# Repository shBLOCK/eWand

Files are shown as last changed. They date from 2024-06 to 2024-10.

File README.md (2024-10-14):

# ⚡eWand: a smart portable electrostatic charge generator

**This project is still highly WIP, as of right now, it does generate charge, but not much control is possible yet.**
<br>
This project is a group project, deriving from my school's project-based learning month.
<br>
Documentation is WIP.

## ⚙️Main features
- Portable
- Fully solid-state operation
- Precisely controllable output
- Output charge measurement (WIP)
- Wireless connectivity
  - Remote configuration & control
  - Data feedback

## Usages
- Physics teaching aid
- ESD testing
- ...

## Notes
- This project is inspired by [Join The Technicians's device](https://www.youtube.com/watch?v=TUDd5lzepgE), but adds more "smart" features to make it more useful as a teaching aid device and for other purposes.

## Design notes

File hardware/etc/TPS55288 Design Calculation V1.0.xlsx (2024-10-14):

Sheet: Design Calculation
Design Tool for TPS55288
V1.0 (06/14/2020)
This tool is designed to aid the user in designing the TPS55288 buck-boost converter. Refer to TPS55288 datasheet for detail design precedure and all equations.
 |  | User input value
 |  | Calculated value
 |  | No use or internal value
Description | Value | Units | Instructions/Comments | Schematic
Component Value
Vin(min) | 3 | V | >=2.7V
Vin(max) | 16 | V | <=36V
Output feedback selection | Internal |  | Select internal feedback or external feedback
Vout | 12.00 | V | Must be lower than or equal to the 1.063x Vout(max)
Vout(max) | 20.0 | V | Select 5V, 10V, 15V, 20V maximum Vout with Vref set to 1.129V
Iout(max) | 5 | A | Maximum output current
Register VREF | 0230 | Hex | Register 00H and 01H value for Vref
VCC | External |  | Select internal VCC or use external VCC power supply
Switching Mode at light load | FPWM |  | Select Forced PWM or Auto PFM mode at light load
I2C address | 74 | Hex | Select I2C slave address
R6 | 51100 | Ω | Mode setting resistor
R7 | 100000.0 | Ω | Up resistor value of the extenral feedback resistor value. It is recommended to 100kΩ
R8 recommended | 5982.7 | Ω | Bottom resistor value of the external feedback resistor divider
Enable Output current limit | Enable |  | Enable output current limit
Iout(limit) | 6.3 | A | Output current limit setting
R1 | 10 | mΩ | Output current sensing resistor
Register 02H | FE | Hex | Register 02H value for current setting. Iout(max)*R1 must be less than 63.5mV
ΔIout(Cout_rms) | 8.66 | Arms | The equivalent output capacitor current ripple spec must be higher than this value.
ΔIin(Cin_rms) | 2.17 | Arms | The equivalent input capacitor current ripple spec must be higher than this value
f(sw) | 394870 | Hz | Typical switching frequency
R2 recommended | 49999.58087 | Ω | Switching frequency setting resistor
Frequency dithering f(mod) | 490 | Hz | Modulation frequency for spread spectrum
C8 recommended | 1.457738167e-08 | F |  | Register Setting
ΔVout(pk-pk) | 0.05 | Vpp | Maximum desired output ripple solely due to output capacitance (ignores ESR)
Cout(min) recommended | 0.0001899359283 | F | Minimum output capacitance needed for Vout ripple requirement | Register Name | Address | b7 | b6 | b5 | b4 | b3 | b2 | b1 | b0 | HEX Value
C2 actual | 1e-05 | F | Effective ceramic capacitance at VOUT. Need to consider the derating with DC bias voltage | VREF_L | 00H | VREF[7] | VREF[6] | VREF[5] | VREF[4] | VREF[3] | VREF[2] | VREF[1] | VREF[0] | 30
 |  |  |  |  |  | 0 | 0 | 1 | 1 | 0 | 0 | 0 | 0
C3 actual | 0.00044 | F | Effective electrolytic capacitance. Need to consider the derating with DC bias voltage | VREF_H | 01H | Reserved | Reserved | Reserved | Reserved | Reserved | Reserved | VREF[9] | VREF[8] | 02
 |  |  |  |  |  | 0 | 0 | 0 | 0 | 0 | 0 | 1 | 0
ESR of C3 | 0.009 | Ω | Equivalent ESR if multiple high ESR electrolytic capacitors in parallel | I_LIMIT | 02H | ILIM_EN | I_LIM[6] | I_LIM[5] | I_LIM[4] | I_LIM[3] | I_LIM[2] | I_LIM[1] | I_LIM[0] | FE
 |  |  |  |  |  | 1 | 1 | 1 | 1 | 1 | 1 | 1 | 0
ΔVin(pk-pk) | 0.05 | Vpp | Maximum desired input ripple due to solely to input capacitance at buck mode | VOUT_SR | 03H | Reserved | Reserved | OCPD[1] | OCPD[0] | Reserved | Reserved | VOSR[1] | VOSR[0] | 31
 |  |  |  |  |  | 0 | 0 | 1 | 1 | 0 | 0 | 0 | 1
Cin(min) recommended | 6.331197609e-05 | F | Minimum input capacitance needed for Vin ripple requirement | VOUT_FS | 04H | FBSEL | Reserved | Reserved | Reserved | Reserved | Reserved | INTFB[1] | INTFB[0] | 03
 |  |  |  |  |  | 0 | 0 | 0 | 0 | 0 | 0 | 1 | 1
Cin actual | 4e-05 | F | effective output capacitance. Need to consider the derating with DC bias voltage when using ceramic cap | CDC | 05H | SCMASK | OCMASK | OVMASK | Reserved | INTCDC | CDC[2] | CDC[1] | CDC[0] | E0
 |  |  |  |  |  | 1 | 1 | 1 | 0 | 0 | 0 | 0 | 0
η estimate | 91.0% |  | Efficiency estimate. Correct it after getting the calculated efficiency | MODE | 06H | OE | FSWDBL | HICCUP | DISCHG | VCCSEL | I2CADD | PFMSEL | MODEST | 39
 |  |  |  |  |  | OFF -0 | DIS -0 | ENA -1 | ENA -1 | EXT -1 | 74H -0 | PFM -0 | INT -1
K | 0.5 |  | Fraction of maximum average inductor current that is ripple current (0.2-0.6 typically) | STATUS | 07H | SCP | OCP | OVP | Reserved | Reserved | Reserved | STATUS1 | STATUS0 | 00
 |  |  |  |  |  | 0 | 0 | 0 | 0 | 0 | 0 | 0 | 0
L1 recommended min | 5.185250842e-07 | H | L1's minimum recommended inductance value to meet inductor current ripple ratio at boost mode with Vin_min
L1 actual | 2.2e-06 | H
I(Lrms) max | 21.99 | Arms | Inductor maximum RMS current
I(Lpeak) max | 23.27 | A | The inductor (L1) is recommended to have saturation current rating 30% higher than this value.
I(Lvalley) max | 20.68 | A
Average Inductor Limit | 16.5 | A | Desired typical average inductor current limit. ±2.5A tolerance
R5 recommended | 20000 | Ω
CDC compensation selection | Internal |  | Internal CDC when using internal Vout feedback. External CDC when using external Vout feedback.
Internal CDC voltage ratio | 0 | mV/mV | ΔVout / (VISP-VISN)
External CDC voltage ratio | 0 | mV/mV | ΔVout / (VISP-VISN)
R4 recommend | floating | Ω | Recommended R4 for external CDC setting
OCP delay time | 12.0 | ms | Set the output current limit response time
VOUT change slew rate | 2.50 | V/ms | Set the output voltage change slew rate during vPPS
Enable SCP indication | Enable |  | Enable or disable the output short circuit indication
Enable OCP indication | Enable |  | Enable or disable the output over current indication
Enable OVP indication | Enable |  | Enable or disable the output over voltage indication
Loop Compensation Calculation in FPWM CCM mode |  |  |  | Bode Plot
Vin | 3.0 | V | Check both buck and boost mode by changing Vin and Vout. The loop must have enough phase margin and gain margin
Vout | 12.0 | V
Buck or Boost? | Boost |  | Calculate open loop compensate at buck mode or boost mode
gm_PS | 19 | S | Power stage gm of IL/Vcomp
fp_PS | 294.7313761 | Hz | Power stage pole of Rload and Cout
fz_RHP | 8986.105116 | Hz | Right half plane zero in boost mode
fz_ESR | 40190.64219 | Hz | ESR zero of the output cap
f(BW) desired | 3000 | Hz | Should be less than 1/5*fzRPH and 1/10*fsw
gm_EA | 0.00019 | S | Error amplifier gm
R3 recommended | 182962.0795 | Ω
R3 actual | 75000 | Ω | COMP pin has internal 2k resistor in seriese with R3
C7 recommended | 6.889824376e-09 | F | Set the compensation fz = fco/10
C7 actual | 6.8e-09 | F
fz_COMP | 303.9628401 | Hz | Loop compensation zero frequency
C6 recommended | 2.446457175e-10 | F | The lower zero of the Cout's ESR zero and boost right half plane zero should be cancelled by the R3*(C6*C7/(C6+C7)) pole
C6 actual | 1e-10 | F
fp2_COMP | 20371.41248 | Hz | Have internal 3pF cap between COMP and GND
Efficiency in buck CCM mode or boost CCM mode with maximum Iout
Vin | 3.7 | V | Vin for efficiency estimation at desired Vout and Iout(max)
I(Lrms) | 17.84 | A | Inductor RMS current
I(Lpeak) | 19.29 | A | Inductor peak current
I(Lvalley) | 16.35 | A | Inductor valley current
DCR of L1 | 0.00255 | Ω | Inductor series resistance per inductor datasheet
Buck HSFET Rdson | 0.0065 | Ω | HSFET on-resistance
Buck HSFET Qg | 7e-09 | C | Total Qg at Vgs=5V
Buck HSFET Coss | 2.7e-10 | F | HSFET output capacitance when VDS=VIN
Buck HSFET rise time | 3.3e-09 | s | Estimate of SW1 node 10-90% rise time from measurement
Buck HSFET fall time | 4.3e-09 | s | Estimate of SW1 node 10-90% fall time from measurement
Buck LSFET Rdson | 0.0065 | Ω | HSFET on-resistance
Buck LSFET Qg | 7e-09 | C | Total Qg at Vgs=5V
Buck LSFET Qrr | 1.72e-08 | C | Reverse recovery charge of the low side FET
Buck LSFET dead time | 1e-08 | s | Dead time during the switching
Buck LSFET diode voltage | 0.7 | V | Estimate of body diode voltage of the HSFET
Boost LSFET Rdson | 0.0071 | Ω | LSFET on-resistance in TPS55288 is 7.1mΩ at 25°C. Temperature coefficient is 0.4%/°C. Correct it when at high Tj
Boost LSFET fall time | 1.3e-08 | s | Estimate of SW node 10-90% fall time from measurement
Boost LSFET rise time | 1.3e-08 | s | Estimate of SW node 10-90% rise time from measurement
Boost HSFET Rdson | 0.0076 | Ω | HSFET on-resistance in TPS55288 is 7.6mΩ at 25°C. Temperature coefficient is 0.4%/°C. Correct it when at high Tj
Boost HSFET dead time | 2e-08 | s | Dead time during the switching
Boost HSFET diode voltage | 1.0 | V | Estimate of body diode voltage of the HSFET
Buck snubber Csnubber | 0 | F | Capacitance of snubber at buck side
Boost snubber Csnubber | 0 | F | Capacitance of snubber at boost side
Rpcb on power path | 2.0 | mΩ | PCB trace resistance on power path from Vin to Vout cap
Rpcb Pd | 636.552483 | mW | Power losses on PCB trace
Inductor DCR Pd | 811.6044158 | mW | Includes losses from DC resistance drop only
Inductor core & AC Pd | 344 | mW | Core and AC loss of inductor. Use inductor vendor's formula to estimate. 344mW is the power loss of XAL1010-472 running at 400kHz with Ilrms=5.21A and Ilripple=2.55A at 400kHz.
TPS55288 Pd | 3879.236161 | mW | Power loss on TPS55288
Rsense Pd | 250 | mW | Power loss on output current sense resistor
Snubber Pd | 0 | mW | Power loss on snubber
Buck HSFET Pd | 2068.79557 | mW | Power loss on buck high side FET
Buck LSFET Pd | 0 | mW | Power loss on buck low side FET
Cout Pd | 489.886869 | mW | Power loss on ESR of the output capacitor in boost mode | 8.8e-08 | 15.88575882 | 38.54611551
η - calculated | 87.6% |  | Efficiency at Iout_max
ΘJA | 37 | °C/W | TPS55288 junction to ambient thermal resistance on EVM. The actual ΘJA depends on the PCB design.
TPS55288 temperature rise | 143.5 | °C | The top case temperature of IC is very close to the Junction temperature because ΨJT=0.6°C/W
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

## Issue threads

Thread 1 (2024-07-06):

EMP interfering debug and sysbus cable signals

shBLOCK, 2024-07-06:
With the current hardware, whenever a discharge pulse happens, the MCU resets.
This is the result of the EMP generating a pulse on the reset line in the debug FPC, this is mostly mitigated by adding a capacitor (eg. 10uF) near the RUN pin to ground.
Further testing is required to see if the sysbus might be interfered in this way.

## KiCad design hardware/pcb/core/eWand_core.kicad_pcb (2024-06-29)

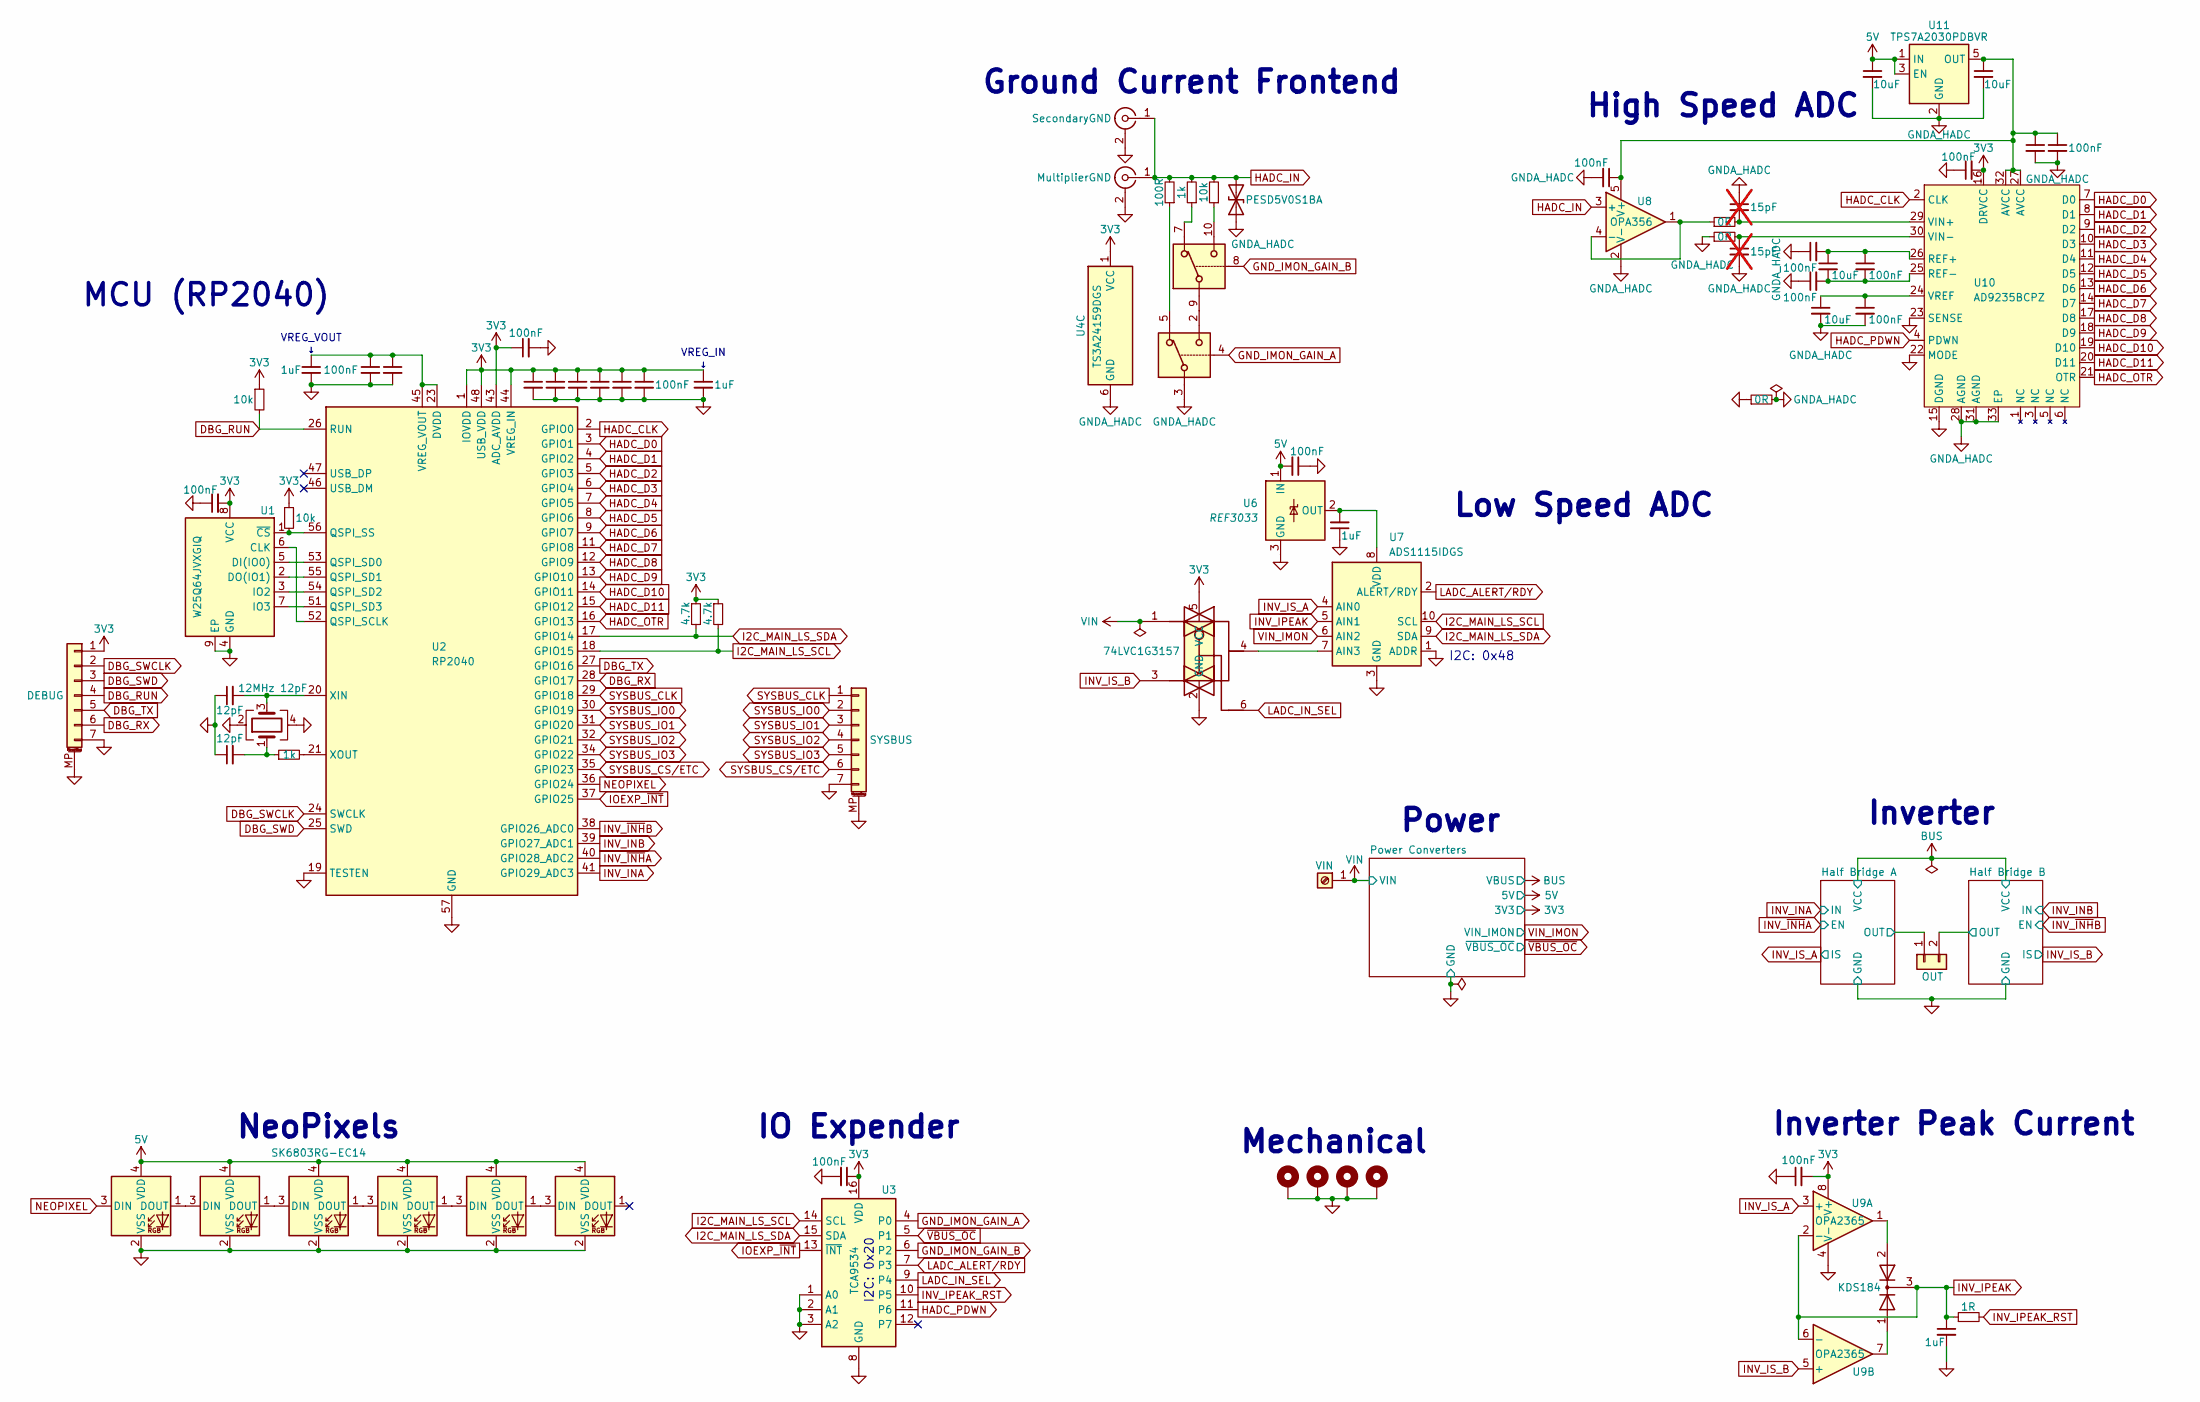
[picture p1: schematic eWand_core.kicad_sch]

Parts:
C1, C5, C6, C7, C8, C9, C10, C11, C12, C13, C15, C16, C18, C21, C22, C23, C26, C27, C30, C32, C33: 100nF; C_0402_1005Metric; LCSC C307331
C2, C3: 12pF; C_0402_1005Metric; LCSC C1547
C4, C14, C17: 1uF; C_0402_1005Metric; LCSC C52923
C19, C20: 15pF; C_0402_1005Metric; LCSC C1548; not fitted
C24, C25, C28, C31: 10uF; C_0402_1005Metric; LCSC C15525
C29: 1uF; C_0805_2012Metric; LCSC C28323
D1, D2, D3, D4, D5, D6: SK6803RG-EC14; LED_SK6812_EC15_1.5x1.5mm; LCSC C18548258
D7: PESD5V0S1BA; D_SOD-323; LCSC C19224
D8: KDS184; SOT-23; LCSC C112694
H1, H2, H3, H4: MountingHole_Pad; MountingHole_2.2mm_M2_Pad_Via
J1: DEBUG; TE_0-1734839-7_1x07-1MP_P0.5mm_Horizontal; LCSC C2911879
J2: SYSBUS; TE_0-1734839-7_1x07-1MP_P0.5mm_Horizontal; LCSC C262232
J3: SecondaryGND; U.FL_Molex_MCRF_73412-0110_Vertical; LCSC C411563
J4: MultiplierGND; U.FL_Molex_MCRF_73412-0110_Vertical; LCSC C411563
J5: VIN; T31000; LCSC C481468
J6: OUT; VH3.96-2AW; LCSC C722831
R1, R2: 10k; R_0402_1005Metric; LCSC C25744
R3: 1k; R_0402_1005Metric; LCSC C11702
R4, R5: 4.7k; R_0402_1005Metric; LCSC C25900
R6: 100R; C_0603_1608Metric; LCSC C22775
R7: 1k; C_0603_1608Metric; LCSC C21190
R8: 10k; C_0603_1608Metric; LCSC C25804
R9, R10: 0R; R_0402_1005Metric; LCSC C17168
R11: 0R; R_0603_1608Metric; LCSC C21189
R12: 1R; R_0402_1005Metric; LCSC C185446
U1: W25Q64JVXGIQ; WSON-8-1EP_4x4mm_P0.8mm_EP2.2x3mm; LCSC C2940195
U2: RP2040; QFN-56-1EP_7x7mm_P0.4mm_EP3.2x3.2mm; LCSC C2040
U3: TCA9534; TSSOP-16_4.4x5mm_P0.65mm; LCSC C206010
U4: TS3A24159DGS; TSSOP-10_3x3mm_P0.5mm; LCSC C129329
U5: 74LVC1G3157; SOT-363_SC-70-6; LCSC C38663
U6: REF3033; SOT-23; LCSC C36658
U7: ADS1115IDGS; TSSOP-10_3x3mm_P0.5mm; LCSC C37593
U8: OPA356; SOT-23-5; LCSC C183100
U9: OPA2365; SOIC-8_3.9x4.9mm_P1.27mm; LCSC C130011
U10: AD9235BCPZ; LFCSP-32-1EP_5x5mm_P0.5mm_EP3.1x3.1mm; LCSC C653330
U11: TPS7A2030PDBVR; SOT-23-5; LCSC C963429
Y1: 12MHz 12pF; Crystal_SMD_3225-4Pin_3.2x2.5mm; LCSC C70565

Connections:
3V3: C1.2, C7.1, C8.1, C9.1, C10.1, C11.1, C12.1, C13.1, C14.1, C15.1, C21.2, C30.2, J1.1, R1.1, R2.1, R4.1, R5.1, U1.8 (VCC), U2.1 (IOVDD), U2.10 (IOVDD), U2.22 (IOVDD), U2.33 (IOVDD), U2.42 (IOVDD), U2.43 (ADC_AVDD), U2.44 (VREG_IN), U2.48 (USB_VDD), U2.49 (IOVDD), U3.16 (VDD), U4.1 (VCC), U5.5 (VCC), U9.8 (V+), U10.16 (DRVCC); also elsewhere on the board
5V: C16.2, C28.1, D1.4 (VDD), D2.4 (VDD), D3.4 (VDD), D4.4 (VDD), D5.4 (VDD), D6.4 (VDD), U6.1 (IN), U11.1 (IN), U11.3 (EN); also elsewhere on the board
/Half Bridge A/OUT: J6.1; also elsewhere on the board
/Half Bridge B/OUT: J6.2; also elsewhere on the board
DBG_RUN: J1.4, R1.2, U2.26 (RUN)
DBG_RX: J1.6, U2.28 (GPIO17)
DBG_SWCLK: J1.2, U2.24 (SWCLK)
DBG_SWD: J1.3, U2.25 (SWD)
DBG_TX: J1.5, U2.27 (GPIO16)
GND: C1.1, C2.1, C3.1, C4.2, C5.2, C6.2, C7.2, C8.2, C9.2, C10.2, C11.2, C12.2, C13.2, C14.2, C15.2, C16.1, C17.1, C21.1, C29.2, C30.1, D1.2 (VSS), D2.2 (VSS), D3.2 (VSS), D4.2 (VSS), D5.2 (VSS), D6.2 (VSS), H1.1, H2.1, H3.1, H4.1, J1.7, J1.MP (MountPin), J2.7, J2.MP (MountPin), J3.2 (Ext), J4.2 (Ext), R11.1, U1.4 (GND), U1.9 (EP), U2.19 (TESTEN), U2.57 (GND), U3.1 (A0), U3.2 (A1), U3.3 (A2), U3.8 (GND), U5.2 (GND), U6.3 (GND), U7.1 (ADDR), U7.3 (GND), U9.4 (V-), U10.15 (DGND), U10.22 (MODE), U10.23 (SENSE), Y1.2, Y1.4; also elsewhere on the board
GNDA_HADC: C18.2, C19.1, C20.2, C22.1, C23.1, C24.2, C27.2, C28.2, C31.2, C32.2, C33.2, D7.1 (A1), R10.1, R11.2, U4.3, U4.6 (GND), U8.2 (V-), U10.28 (AGND), U10.31 (AGND), U10.33 (EP), U11.2 (GND)
GND_IMON_GAIN_A: U3.4 (P0), U4.4
GND_IMON_GAIN_B: U3.6 (P2), U4.8
HADC_CLK: U2.2 (GPIO0), U10.2 (CLK)
HADC_D0: U2.3 (GPIO1), U10.7 (D0)
HADC_D1: U2.4 (GPIO2), U10.8 (D1)
HADC_D2: U2.5 (GPIO3), U10.9 (D2)
HADC_D3: U2.6 (GPIO4), U10.10 (D3)
HADC_D4: U2.7 (GPIO5), U10.11 (D4)
HADC_D5: U2.8 (GPIO6), U10.12 (D5)
HADC_D6: U2.9 (GPIO7), U10.13 (D6)
HADC_D7: U2.11 (GPIO8), U10.14 (D7)
HADC_D8: U2.12 (GPIO9), U10.17 (D8)
HADC_D9: U2.13 (GPIO10), U10.18 (D9)
HADC_D10: U2.14 (GPIO11), U10.19 (D10)
HADC_D11: U2.15 (GPIO12), U10.20 (D11)
HADC_IN: D7.2 (A2), J3.1 (In), J4.1 (In), R6.2, R7.2, R8.2, U8.3 (+)
HADC_OTR: U2.16 (GPIO13), U10.21 (OTR)
HADC_PDWN: U3.11 (P6), U10.4 (PDWN)
I2C_MAIN_LS_SCL: R5.2, U2.18 (GPIO15), U3.14 (SCL), U7.10 (SCL); also elsewhere on the board
I2C_MAIN_LS_SDA: R4.2, U2.17 (GPIO14), U3.15 (SDA), U7.9 (SDA); also elsewhere on the board
INV_INA: U2.41 (GPIO29_ADC3); also elsewhere on the board
INV_INB: U2.39 (GPIO27_ADC1); also elsewhere on the board
INV_IPEAK: C29.1, D8.3 (K), R12.1, U7.5 (AIN1), U9.2 (-), U9.6 (-)
INV_IPEAK_RST: R12.2, U3.10 (P5)
INV_IS_A: U7.4 (AIN0), U9.3 (+); also elsewhere on the board
INV_IS_B: U5.3, U9.5 (+); also elsewhere on the board
INV_~INHA: U2.40 (GPIO28_ADC2); also elsewhere on the board
INV_~INHB: U2.38 (GPIO26_ADC0); also elsewhere on the board
IOEXP_~INT: U2.37 (GPIO25), U3.13 (~INT)
LADC_ALERT/RDY: U3.7 (P3), U7.2 (ALERT/RDY)
LADC_IN_SEL: U3.9 (P4), U5.6
NEOPIXEL: D1.3 (DIN), U2.36 (GPIO24)
unnamed: C3.2, R3.1, Y1.1
unnamed: D1.1 (DOUT), D2.3 (DIN)
unnamed: D2.1 (DOUT), D3.3 (DIN)
unnamed: D3.1 (DOUT), D4.3 (DIN)
unnamed: D4.1 (DOUT), D5.3 (DIN)
unnamed: D5.1 (DOUT), D6.3 (DIN)
unnamed: D8.1 (A), U9.7
unnamed: D8.2 (A), U9.1
unnamed: R6.1, U4.5
unnamed: R7.1, U4.7
unnamed: R8.1, U4.10
unnamed: U1.6 (CLK), U2.52 (QSPI_SCLK)
unnamed: U1.5 (DI(IO0)), U2.53 (QSPI_SD0)
unnamed: U1.2 (DO(IO1)), U2.55 (QSPI_SD1)
unnamed: U1.3 (IO2), U2.54 (QSPI_SD2)
unnamed: U1.7 (IO3), U2.51 (QSPI_SD3)
unnamed: R2.2, U1.1 (~CS), U2.56 (QSPI_SS)
unnamed: C4.1, C5.1, C6.1, U2.23 (DVDD), U2.45 (VREG_VOUT), U2.50 (DVDD)
unnamed: C2.2, U2.20 (XIN), Y1.3
unnamed: R3.2, U2.21 (XOUT)
unnamed: U4.2, U4.9
unnamed: C17.2, U6.2 (OUT), U7.8 (VDD)
unnamed: U5.4, U7.7 (AIN3)
unnamed: R9.1, U8.1, U8.4 (-)
unnamed: C22.2, C25.1, C26.1, U10.26 (REF+)
unnamed: C23.2, C25.2, C26.2, U10.25 (REF-)
unnamed: C19.2, R9.2, U10.29 (VIN+)
unnamed: C20.1, R10.2, U10.30 (VIN-)
unnamed: C24.1, C27.1, U10.24 (VREF)
unnamed: C18.1, C31.1, C32.1, C33.1, U8.5 (V+), U10.27 (AVCC), U10.32 (AVCC), U11.5 (OUT)
SYSBUS_CLK: J2.1, U2.29 (GPIO18)
SYSBUS_CS/ETC: J2.6, U2.35 (GPIO23)
SYSBUS_IO0: J2.2, U2.30 (GPIO19)
SYSBUS_IO1: J2.3, U2.31 (GPIO20)
SYSBUS_IO2: J2.4, U2.32 (GPIO21)
SYSBUS_IO3: J2.5, U2.34 (GPIO22)
VIN: J5.1, U5.1; also elsewhere on the board
VIN_IMON: U7.6 (AIN2); also elsewhere on the board
~VBUS_OC: U3.5 (P1); also elsewhere on the board

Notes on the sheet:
Inverter Peak Current
High Speed ADC
Ground Current Frontend
Inverter
Power
VREG_IN ↓
VREG_VOUT ↓
Low Speed ADC
I2C: 0x20
IO Expender
Mechanical
NeoPixels
I2C: 0x48
MCU (RP2040)

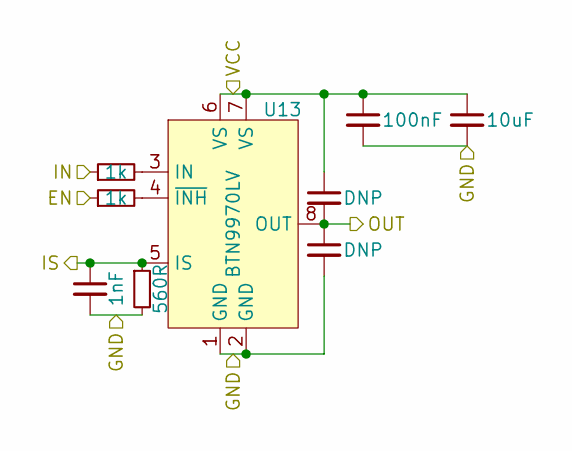
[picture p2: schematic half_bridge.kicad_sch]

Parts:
C39: 1nF; C_0402_1005Metric; LCSC C1523
C40, C41: DNP; C_0805_2012Metric
C42: 100nF; C_0402_1005Metric; LCSC C307331
C43: 10uF; C_1206_3216Metric; LCSC C13585
R16, R17: 1k; R_0402_1005Metric; LCSC C11702
R18: 560R; R_0402_1005Metric; LCSC C25126
U13: BTN9970LV; PG-HSOF-7-1; LCSC C3655537

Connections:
/Half Bridge B/OUT: C40.2, C41.1, U13.8 (OUT); also elsewhere on the board
BUS: C40.1, C42.1, C43.1, U13.6 (VS), U13.7 (VS); also elsewhere on the board
GND: C39.2, C41.2, C42.2, C43.2, R18.2, U13.1 (GND), U13.2 (GND); also elsewhere on the board
INV_INB: R16.1; also elsewhere on the board
INV_IS_B: C39.1, R18.1, U13.5 (IS); also elsewhere on the board
INV_~INHB: R17.1; also elsewhere on the board
unnamed: R16.2, U13.3 (IN)
unnamed: R17.2, U13.4 (~INH)

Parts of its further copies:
C34: 1nF; C_0402_1005Metric; LCSC C1523
C35, C36: DNP; C_0805_2012Metric
C37: 100nF; C_0402_1005Metric; LCSC C307331
C38: 10uF; C_1206_3216Metric; LCSC C13585
R13, R14: 1k; R_0402_1005Metric; LCSC C11702
R15: 560R; R_0402_1005Metric; LCSC C25126
U12: BTN9970LV; PG-HSOF-7-1; LCSC C3655537

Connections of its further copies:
/Half Bridge A/OUT: C35.2, C36.1, U12.8 (OUT); also elsewhere on the board
BUS: C35.1, C37.1, C38.1, U12.6 (VS), U12.7 (VS); also elsewhere on the board
GND: C34.2, C36.2, C37.2, C38.2, R15.2, U12.1 (GND), U12.2 (GND); also elsewhere on the board
INV_INA: R13.1; also elsewhere on the board
INV_IS_A: C34.1, R15.1, U12.5 (IS); also elsewhere on the board
INV_~INHA: R14.1; also elsewhere on the board
unnamed: R13.2, U12.3 (IN)
unnamed: R14.2, U12.4 (~INH)

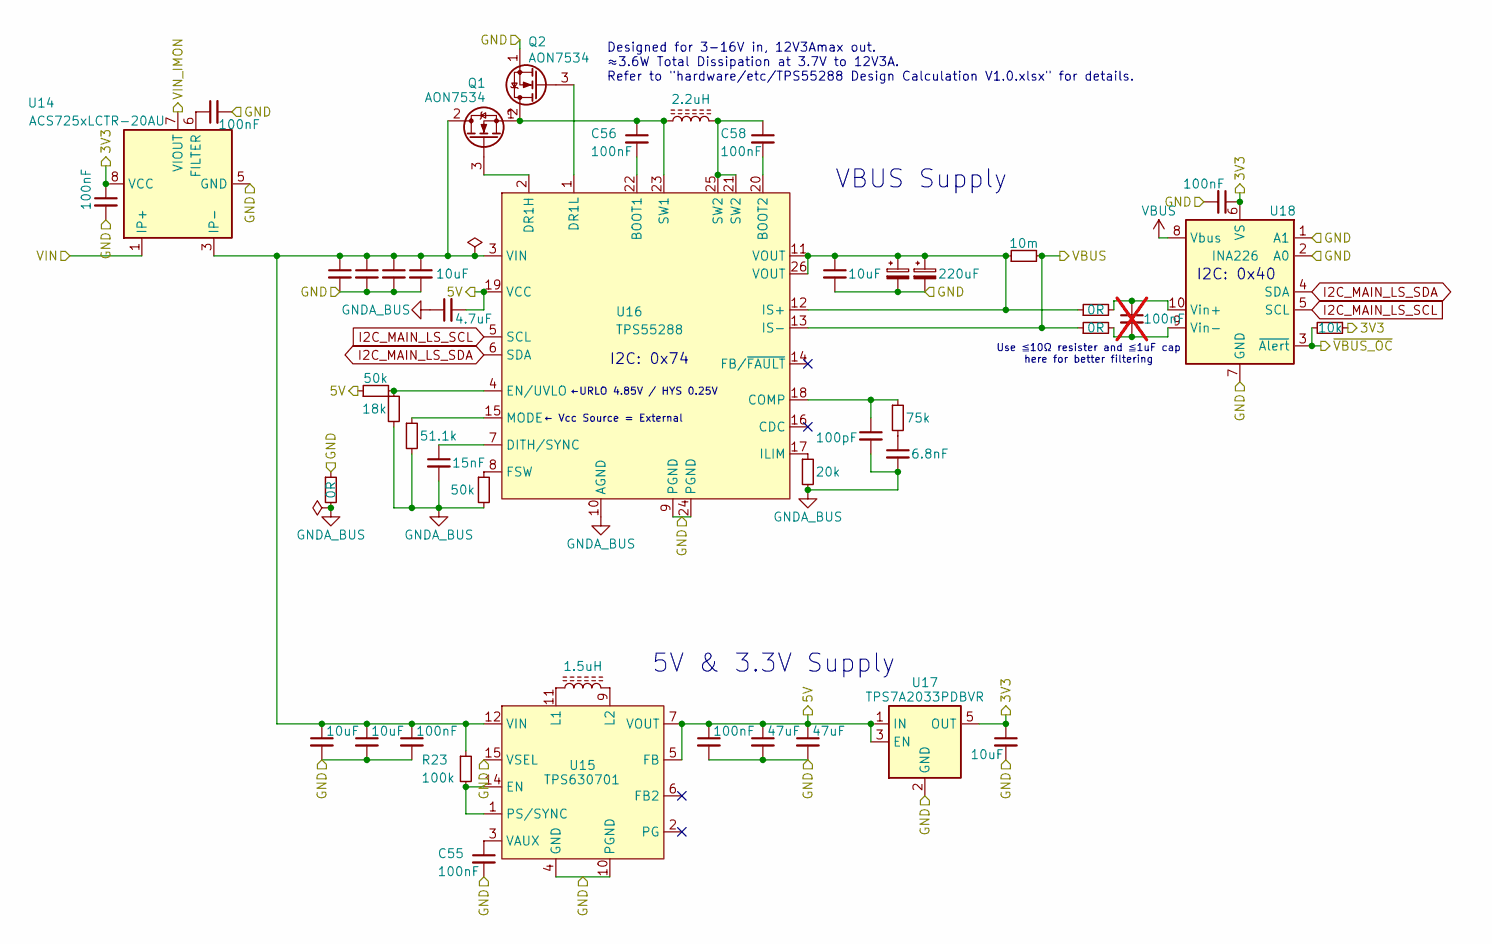
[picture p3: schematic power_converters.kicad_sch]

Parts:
C44, C45, C51, C55, C56, C57, C58, C68: 100nF; C_0402_1005Metric; LCSC C307331
C46, C47, C48, C49, C50, C52: 10uF; C_0805_2012Metric; LCSC C15850
C53: 15nF; C_0402_1005Metric; LCSC C114405
C54: 4.7uF; C_0402_1005Metric; LCSC C318563
C59, C60: 47uF; C_0805_2012Metric; LCSC C16780
C61: 10uF; C_1206_3216Metric; LCSC C13585
C62: 100pF; C_0402_1005Metric; LCSC C1546
C63: 220uF; CP_Radial_D6.3mm_P2.50mm_L8mm_Horizontal; LCSC C2943986
C64: 6.8nF; C_0402_1005Metric; LCSC C1542
C65: 220uF; CP_Radial_D6.3mm_P2.50mm_L8mm_Horizontal_Fli; LCSC C2943986
C66: 10uF; C_0402_1005Metric; LCSC C15525
C67: 100nF; C_0402_1005Metric; LCSC C307331; not fitted
L1: 1.5uH; L_Changjiang_FNR252012S; LCSC C5832371
L2: 2.2uH; L_Coilcraft_XAL1010-XXX; LCSC C5125746
Q1, Q2: AON7534; DFN-8_3x3; LCSC C115844
R19: 0R; R_0603_1608Metric; LCSC C21189
R20, R24: 50k; R_0402_1005Metric; LCSC C166559
R21: 18k; R_0402_1005Metric; LCSC C25762
R22: 51.1k; R_0402_1005Metric; LCSC C284602
R23: 100k; R_0402_1005Metric; LCSC C25741
R25: 20k; R_0402_1005Metric; LCSC C25765
R26: 75k; R_0402_1005Metric; LCSC C25798
R27: 10m; R_1206_3216Metric; LCSC C2961483
R28, R29: 0R; R_0402_1005Metric; LCSC C17168
R30: 10k; R_0402_1005Metric; LCSC C25744
U14: ACS725xLCTR-20AU; SOIC-8_3.9x4.9mm_P1.27mm; LCSC C459335
U15: TPS630701; VQFN-HR-15; LCSC C2876599
U16: TPS55288; RPM0026A-MFG; LCSC C2876595
U17: TPS7A2033PDBVR; SOT-23-5; LCSC C2862740
U18: INA226; VSSOP-10_3x3mm_P0.5mm; LCSC C49851

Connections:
3V3: C44.1, C66.1, C68.1, R30.1, U14.8 (VCC), U17.5 (OUT), U18.6 (VS); also elsewhere on the board
5V: C54.2, C57.1, C59.1, C60.1, R20.1, U15.5 (FB), U15.7 (VOUT), U16.19 (VCC), U17.1 (IN), U17.3 (EN); also elsewhere on the board
BUS: R27.2, R29.1, U16.13 (IS-), U18.8 (Vbus); also elsewhere on the board
GND: C44.2, C45.2, C46.2, C47.2, C48.2, C49.2, C50.2, C51.2, C52.2, C55.2, C57.2, C59.2, C60.2, C61.2, C63.2, C65.2, C66.2, C68.2, Q2.1 (S), R19.1, U14.5 (GND), U15.4 (GND), U15.10 (PGND), U15.15 (VSEL), U16.9 (PGND), U16.24 (PGND), U17.2 (GND), U18.1 (A1), U18.2 (A0), U18.7 (GND); also elsewhere on the board
GNDA_BUS: C53.2, C54.1, C62.2, C64.2, R19.2, R21.2, R22.2, R24.2, R25.2, U16.10 (AGND)
I2C_MAIN_LS_SCL: U16.5 (SCL), U18.5 (SCL); also elsewhere on the board
I2C_MAIN_LS_SDA: U16.6 (SDA), U18.4 (SDA); also elsewhere on the board
unnamed: C58.1, L2.2, U16.21 (SW2), U16.25 (SW2)
unnamed: C64.1, R26.2
unnamed: C46.1, C47.1, C48.1, C49.1, C50.1, C51.1, C52.1, Q1.2 (D), R23.1, U14.3 (IP-), U14.4 (IP-), U15.12 (VIN), U16.3 (VIN)
unnamed: Q1.3 (G), U16.2 (DR1H)
unnamed: C56.1, L2.1, Q1.1 (S), Q2.2 (D), U16.23 (SW1)
unnamed: Q2.3 (G), U16.1 (DR1L)
unnamed: C45.1, U14.6 (FILTER)
unnamed: R23.2, U15.1 (PS/SYNC), U15.14 (EN)
unnamed: L1.1, U15.11 (L1)
unnamed: L1.2, U15.9 (L2)
unnamed: C55.1, U15.3 (VAUX)
unnamed: C56.2, U16.22 (BOOT1)
unnamed: C58.2, U16.20 (BOOT2)
unnamed: C62.1, R26.1, U16.18 (COMP)
unnamed: C53.1, U16.7 (DITH/SYNC)
unnamed: R20.2, R21.1, U16.4 (EN/UVLO)
unnamed: R24.1, U16.8 (FSW)
unnamed: R25.1, U16.17 (ILIM)
unnamed: C61.1, C63.1, C65.1, R27.1, R28.1, U16.11 (VOUT), U16.12 (IS+), U16.26 (VOUT)
unnamed: R22.1, U16.15 (MODE)
unnamed: C67.1, R28.2, U18.10 (Vin+)
unnamed: C67.2, R29.2, U18.9 (Vin-)
VIN: U14.1 (IP+), U14.2 (IP+); also elsewhere on the board
VIN_IMON: U14.7 (VIOUT); also elsewhere on the board
~VBUS_OC: R30.2, U18.3 (~Alert); also elsewhere on the board

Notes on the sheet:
Use ≦10Ω resister and ≦1uF cap here for better filtering
5V & 3.3V Supply
I2C: 0x74
Designed for 3-16V in, 12V3Amax out. ≈3.6W Total Dissipation at 3.7V to 12V3A. Refer to "hardware/etc/TPS55288 Design Calculation V1.0.xlsx" for details.
←URLO 4.85V / HYS 0.25V
← Vcc Source = External
VBUS Supply
I2C: 0x40

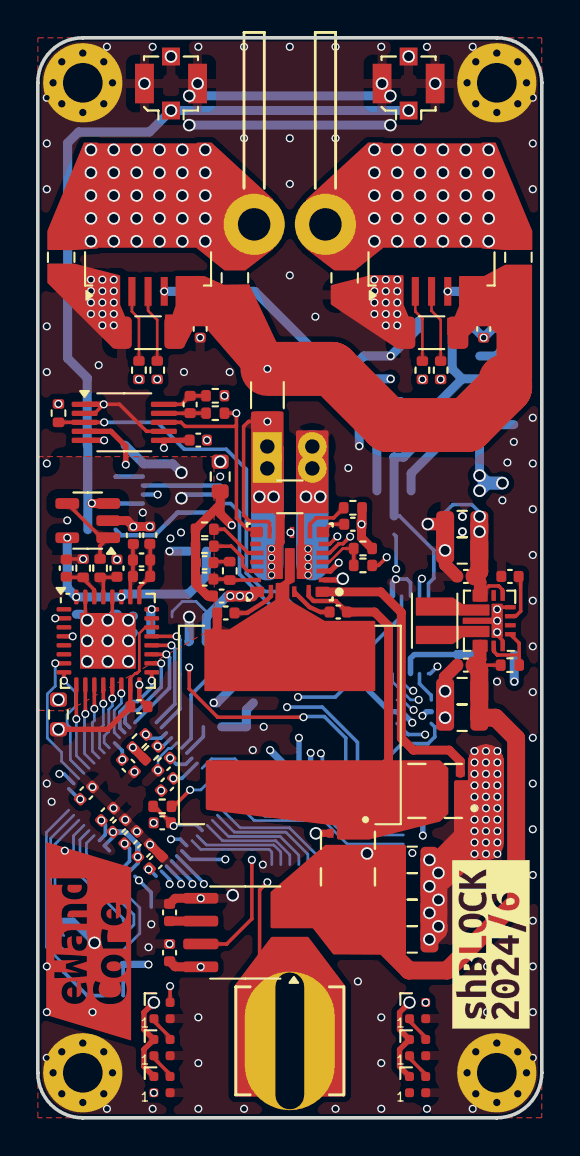
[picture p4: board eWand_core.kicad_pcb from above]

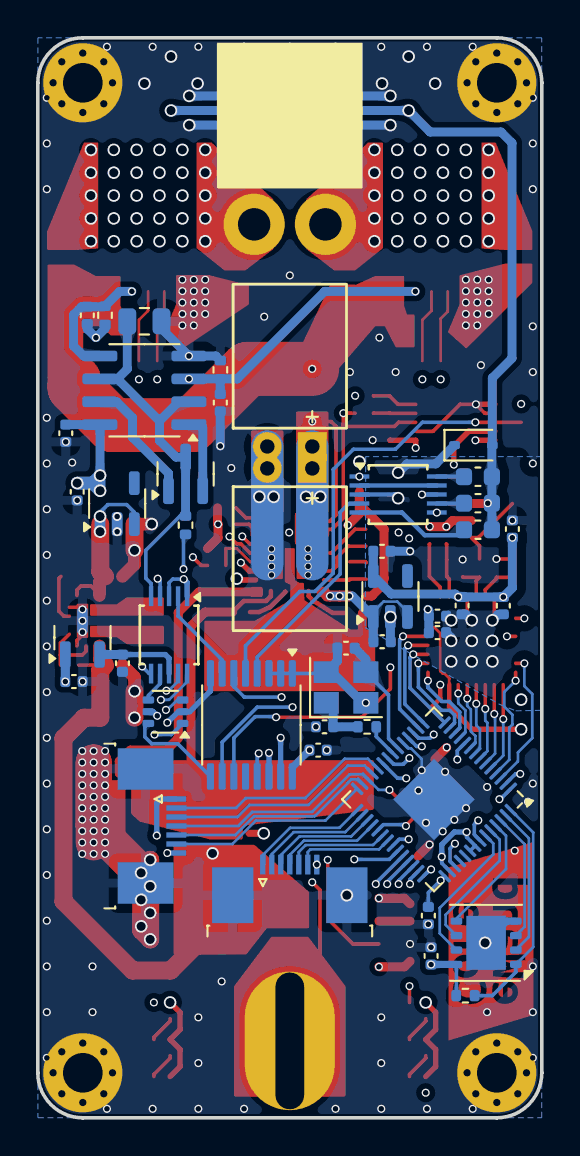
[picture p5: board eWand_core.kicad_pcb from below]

Board: 6 copper layers, 28.0 x 60.0 mm, 141 parts (44 on the bottom side), 110 nets.

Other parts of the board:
kibuzzard-6674E35D: G***; kibuzzard-6674E35D
kibuzzard-66739BFE: G***; kibuzzard-66739BFE

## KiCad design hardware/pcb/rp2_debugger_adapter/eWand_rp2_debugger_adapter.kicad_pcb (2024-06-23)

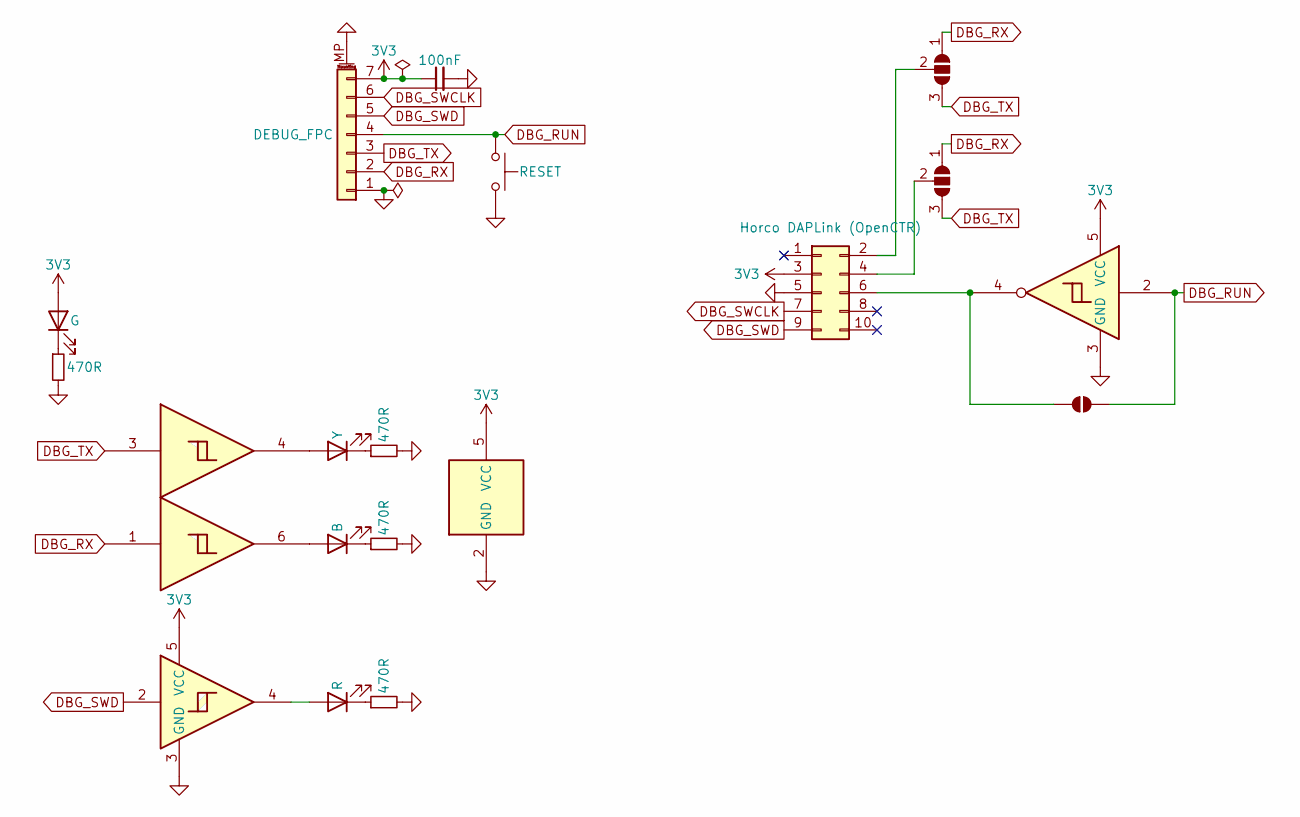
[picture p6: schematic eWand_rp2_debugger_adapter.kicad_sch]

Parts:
C1: 100nF; C_0402_1005Metric; LCSC C307331
D1: R; LED_0603_1608Metric; LCSC C84263
D2: Y; LED_0603_1608Metric; LCSC C84268
D3: B; LED_0603_1608Metric; LCSC C84266
D4: G; LED_0603_1608Metric; LCSC C84267
J1: DEBUG_FPC; TE_0-1734839-7_1x07-1MP_P0.5mm_Horizontal; LCSC C2911968
J2: Horco DAPLink (OpenCTR); PinSocket_2x05_P2.54mm_Horizontal; LCSC C2897425
JP1, JP2: SolderJumper_3_Open; SolderJumper-3_P1.3mm_Open_RoundedPad1.0x1.5mm
JP3: SolderJumper_2_Open; SolderJumper-2_P1.3mm_Open_RoundedPad1.0x1.5mm
R1, R2, R3, R4: 470R; R_0603_1608Metric; LCSC C23179
SW1: RESET; SW_SPST_CK_RS282G05A3; LCSC C318938
U1: SN74LVC1G14DBV; SOT-23-5; LCSC C7835
U2: 74LVC2G17; SOT-23-6; LCSC C10429
U4: 74LVC1G17; SOT-23-5; LCSC C7836

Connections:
3V3: C1.1, D4.2 (A), J1.7, J2.3, U1.5 (VCC), U2.5 (VCC), U4.5 (VCC)
DBG_RUN: J1.4, JP3.2 (B), SW1.1, U1.2
DBG_RX: J1.2, JP1.1 (A), JP2.1 (A), U2.1
DBG_SWCLK: J1.6, J2.7
DBG_SWD: J1.5, J2.9, U4.2
DBG_TX: J1.3, JP1.3 (B), JP2.3 (B), U2.3
GND: C1.2, J1.1, J1.MP (MountPin), J2.5, R1.2, R2.2, R3.2, R4.2, SW1.2, U1.3 (GND), U2.2 (GND), U4.3 (GND)
unnamed: D1.2 (A), U4.4
unnamed: D1.1 (K), R1.1
unnamed: D2.2 (A), U2.4
unnamed: D2.1 (K), R2.1
unnamed: D3.2 (A), U2.6
unnamed: D3.1 (K), R3.1
unnamed: D4.1 (K), R4.1
unnamed: J2.2, JP1.2 (C)
unnamed: J2.4, JP2.2 (C)
unnamed: J2.6, JP3.1 (A), U1.4

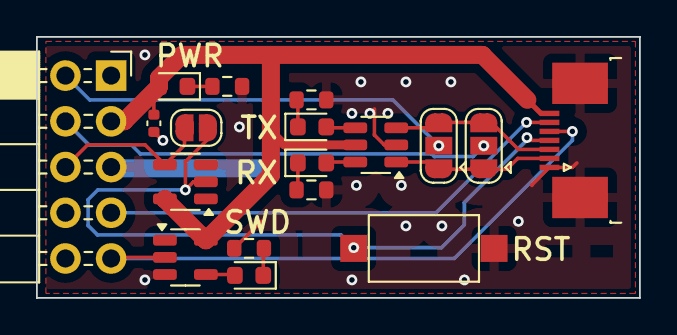
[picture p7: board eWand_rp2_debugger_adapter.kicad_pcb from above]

Board: 2 copper layers, 33.5 x 14.5 mm, 18 parts (0 on the bottom side), 17 nets.

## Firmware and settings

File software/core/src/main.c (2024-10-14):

/**
 * Copyright (c) 2020 Raspberry Pi (Trading) Ltd.
 *
 * SPDX-License-Identifier: BSD-3-Clause
 */

#include <stdio.h>
#include "hardware/vreg.h"
#include "pico/stdlib.h"
#include "pico/multicore.h"
#include "pico/rand.h"
#include "pico/time.h"
#include "hardware/watchdog.h"

#include "misc/i2c_bus.h"
#include "misc/io_exp.h"
#include "power_stage/power_stage.h"
#include "hadc/hadc.h"
#include "misc/neopixel.h"
#include "dcdc/dcdc.h"
#include "misc/power_monitor.h"

void main_core1();

int main() {
    stdio_init_all();

    printf("CHIP_RESET: %x\n", vreg_and_chip_reset_hw->chip_reset);
    if (vreg_and_chip_reset_hw->chip_reset & (1 << 16)) {
        printf("Reset: RUN Pin\n");
    }
    if (vreg_and_chip_reset_hw->chip_reset & (1 << 8)) {
        printf("Reset: Power\n");
    }
    if (vreg_and_chip_reset_hw->chip_reset & (1 << 20)) {
        printf("Reset: Debug Port (PSM reset)\n");
    }
    if (vreg_and_chip_reset_hw->chip_reset & (1 << 24)) {
        printf("PSM_RESTART_FLAG set\n");
    }

    i2c_bus_init();
    i2c_bus_debug_scan();
    neopixel_init();
    neopixel_upload();

    multicore_reset_core1();
    multicore_launch_core1(main_core1);

    power_monitor_init();

    // Notify init done
    multicore_fifo_pop_blocking();
    multicore_fifo_push_blocking(0);

    printf("Initialization complete!\n");

    while (true) {
        printf("BUS Voltage: %.2f\n", power_monitor_get_voltage());
        printf("BUS Current: %.2f\n", power_monitor_get_current());
        sleep_ms(1000);
    }
    // uint8_t intensity = 0;
    // while (true) {
    //     neopixel_set_rgb(0, intensity, 0, 0);
    //     neopixel_set_rgb(1, 0, intensity, 0);
    //     neopixel_set_rgb(2, 0, 0, intensity);
    //     neopixel_upload();
    //     intensity++;
    //     // sleep_ms(1);
    // }
}

#define D_V 12.f

void main_core1() {
    io_exp_init();
    dcdc_init();

    // hadc_init();
    power_stage_init();

    // Notify init done
    multicore_fifo_push_blocking(0);
    multicore_fifo_pop_blocking();

    // dcdc_set_output_enable(false);
    // sleep_ms(3000);
    dcdc_set_voltage(D_V);
    dcdc_set_output_enable(true);

    power_stage_set_enable(false);
    power_stage_set_output_params(4000-1, 4000);

    while (true) {
        while (true) {
            const char in = getchar_timeout_us(0);
            if (in == PICO_ERROR_TIMEOUT)
                break;
            if (in == ';') {
                power_stage_set_enable(true);
                dcdc_set_voltage(D_V);
                dcdc_set_output_enable(true);
                printf("Output Enabled\n");
            } else if (in == '\'') {
                power_stage_set_enable(false);
                printf("Output Disabled\n");
            }
        }

        // power_stage_set_enable(true);
        // dcdc_set_voltage(D_V);
        // dcdc_set_output_enable(true);

        const uint dcdc_err = dcdc_get_err();
        if (dcdc_err) {
            printf("DCDC Error: %u\n", dcdc_get_err());
        }
        // dcdc_set_voltage(D_V);
        sleep_ms(10);
    }
}

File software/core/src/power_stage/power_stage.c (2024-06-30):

#include <stdio.h>

#include "pico/stdlib.h"
#include "hardware/pwm.h"
#include "hardware/dma.h"
#include "utils/utils.h"

#include "power_stage.h"

#define PS_PIN_INV_INA 29
#define PS_PIN_INV_INB 27
#define PS_PIN_INV_ENA 28
#define PS_PIN_INV_ENB 26

// debug: output to LED
#if false
#undef PS_PIN_INV_INA
#define PS_PIN_INV_INA 25
#endif

const uint PS_PINS_INV_IN[] = {PS_PIN_INV_INA, PS_PIN_INV_INB};
const uint PS_PINS_INV_EN[] = {PS_PIN_INV_ENA, PS_PIN_INV_ENB};

static uint PS_PWM_SLICE[2];
static enum pwm_chan PS_PWM_CHAN[2];
static uint PS_DMA_CTRL;
static uint PS_DMA_CTRLRST;
static uint PS_DMA_DATA;

typedef struct __packed_aligned {
    uint16_t cc;
    uint16_t top;
} output_params;
static volatile output_params pwm_cfg; // to ensure atomic write from MCU
static volatile output_params pwm_cfg_buf; // double buffering, DMA reads from this

static uint8_t dummy = 0;
const static uint32_t ZERO32 = 0;
const static uint32_t CTRLRST_TRANS_COUNT_TRIG = 1;
static volatile struct __packed_aligned {
    volatile const void* read_addr;
    volatile void* write_addr;
    uint32_t trans_count;
    uint32_t ctrl;
} control_blocks[] = { // ctrl values to be configured in power_stage_init()
    {&pwm_cfg, &pwm_cfg_buf, 1, 0}, // copy pwm_cfg to pwm_cfg_buf atomically
    {&pwm_cfg_buf.top, NULL, 1, 0}, // configure PWM A top
    {&pwm_cfg_buf.top, NULL, 1, 0}, // configure PWM B top
    {&pwm_cfg_buf.cc, NULL, 1, 0}, // configure PWM A cc
    {&ZERO32, NULL, 1, 0}, // configure PWM B cc
    {&dummy, &dummy, 1, 0}, // wait for the next PWM wrap
    {&ZERO32, NULL, 1, 0}, // configure PWM A cc
    {&pwm_cfg_buf.cc, NULL, 1, 0}, // configure PWM B cc
    {&CTRLRST_TRANS_COUNT_TRIG, NULL, 1, 0}, // trigger PS_DMA_CTRLRST
};
const static volatile void* CTRL_READ_ADDR_TRIG = &control_blocks[0];

void power_stage_init() {
    printf("Initializing PowerStage...\n");

    // INH Pins: GPIO
    for (int i = 0; i < 2; ++i) {
        const uint pin = PS_PINS_INV_EN[i];
        gpio_init(pin);
        gpio_put(pin, false);
        gpio_strong_output(pin);
    }

    // IN Pins: PWM
    uint pwm_en_mask = 0;
    for (int i = 0; i < 2; ++i) {
        const uint pin = PS_PINS_INV_IN[i];
        gpio_set_function(pin, GPIO_FUNC_PWM);
        gpio_strong_output(pin);
        const uint slice = pwm_gpio_to_slice_num(pin);
        PS_PWM_SLICE[i] = slice;
        const enum pwm_chan chan = pwm_gpio_to_channel(pin);
        PS_PWM_CHAN[i] = chan;

        pwm_config cfg = pwm_get_default_config();
        pwm_config_set_clkdiv_int(&cfg, 1);
        pwm_init(slice, &cfg, false);
        pwm_set_chan_level(slice, chan, 0);
        pwm_en_mask |= 1 << slice;
    }
    // Enable the two PWM in sync
    pwm_set_mask_enabled(pwm_en_mask);

    power_stage_set_output_params(0xFFFF - 1, 0);


    // PWM DMAs
    // Note: PWM hardware has double-buffering,
    //       so we only need to finish reconfiguring the two PWM slices before the next wrap.
    {
        PS_DMA_CTRL = dma_claim_unused_channel(true);
        PS_DMA_CTRLRST = dma_claim_unused_channel(true);
        PS_DMA_DATA = dma_claim_unused_channel(true);

        // setup control blocks
        {
            // buffer pwm_cfg value
            dma_channel_config cfg = dma_channel_get_default_config(PS_DMA_DATA);
            channel_config_set_chain_to(&cfg, PS_DMA_CTRL);
            channel_config_set_transfer_data_size(&cfg, DMA_SIZE_32);
            channel_config_set_read_increment(&cfg, true);
            channel_config_set_write_increment(&cfg, true);
            control_blocks[0].ctrl = channel_config_get_ctrl_value(&cfg);

            // configure PWM
            cfg = dma_channel_get_default_config(PS_DMA_DATA);
            channel_config_set_chain_to(&cfg, PS_DMA_CTRL);
            channel_config_set_transfer_data_size(&cfg, DMA_SIZE_16);
            channel_config_set_read_increment(&cfg, true);
            channel_config_set_write_increment(&cfg, true);
            for (int i = 0; i < 2; ++i) {
                const uint base_index = 1;
                control_blocks[base_index + i].write_addr = &pwm_hw->slice[PS_PWM_SLICE[i]].top;
                control_blocks[base_index + i].ctrl = channel_config_get_ctrl_value(&cfg);
            }
            for (int base_i = 0; base_i < 2; ++base_i) {
                const uint bases[] = {3, 6};
                const uint base_index = bases[base_i];
                for (int i = 0; i < 2; ++i) {
                    control_blocks[base_index + i].write_addr = (void*) &pwm_hw->slice[PS_PWM_SLICE[i]].cc + 2 * PS_PWM_CHAN[i];
                    control_blocks[base_index + i].ctrl = channel_config_get_ctrl_value(&cfg);
                }
            }

            // wait for the next PWM wrap
            cfg = dma_channel_get_default_config(PS_DMA_DATA);
            channel_config_set_chain_to(&cfg, PS_DMA_CTRL);
            channel_config_set_transfer_data_size(&cfg, DMA_SIZE_8);
            channel_config_set_dreq(&cfg, pwm_get_dreq(PS_PWM_SLICE[0]));
            control_blocks[5].ctrl = channel_config_get_ctrl_value(&cfg);

            // trigger PS_DMA_CTRLRST
            cfg = dma_channel_get_default_config(PS_DMA_DATA);
            channel_config_set_transfer_data_size(&cfg, DMA_SIZE_32);
            channel_config_set_read_increment(&cfg, true);
            channel_config_set_write_increment(&cfg, true);
            control_blocks[count_of(control_blocks) - 1].write_addr = &dma_hw->ch[PS_DMA_CTRLRST].al1_transfer_count_trig;
            control_blocks[count_of(control_blocks) - 1].ctrl = channel_config_get_ctrl_value(&cfg);
        }

        // master (control) DMA
        {
            dma_channel_config cfg = dma_channel_get_default_config(PS_DMA_CTRL);
            channel_config_set_transfer_data_size(&cfg, DMA_SIZE_32);
            channel_config_set_read_increment(&cfg, true);
            channel_config_set_write_increment(&cfg, true);
            channel_config_set_ring(&cfg, true, 4); // 16 byte, 4 words
            dma_channel_configure(
                PS_DMA_CTRL,
                &cfg,
                &dma_hw->ch[PS_DMA_DATA].read_addr, // write to the 4 alt0 regs
                NULL, // configured by PS_DMA_CTRLRST
                4,
                false
            );
        }

        // control reset (CTRLRST) DMA
        {
            dma_channel_config cfg = dma_channel_get_default_config(PS_DMA_CTRLRST);
            channel_config_set_dreq(&cfg, pwm_get_dreq(PS_PWM_SLICE[0]));
            channel_config_set_transfer_data_size(&cfg, DMA_SIZE_32);
            channel_config_set_read_increment(&cfg, false);
            channel_config_set_write_increment(&cfg, false);
            dma_channel_configure(
                PS_DMA_CTRLRST,
                &cfg,
                &dma_hw->ch[PS_DMA_CTRL].al3_read_addr_trig,
                &CTRL_READ_ADDR_TRIG,
                1,
                true // start the entire DMA contraption
            );
        }
    }
}
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

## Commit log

2024-06-24 Save old progress before switching to using PWM instead of PIO for power stage.
2024-06-29 I2C Bus IO Expander
2024-06-29 Update pcb
    [eWand_core.kicad_pcb]
2024-06-29 High speed ADC initial version (not validated)
2024-06-30 Power stage PWM implementation
2024-06-30 I2C bus 16bit operations
2024-10-14 Upload current progress (see detailed message), development is pause for now...
    [TPS55288 Design Calculation V1.0.xlsx]
